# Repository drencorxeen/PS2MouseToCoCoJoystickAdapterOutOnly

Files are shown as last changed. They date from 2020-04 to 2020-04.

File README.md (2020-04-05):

# PS2MouseToCoCoJoystickPortAdapterOutOnly
This project is design to take a PS/2 Mouse and convert it to be usable on a Tandy Radio Shack Color Computer's joystick port.

## Requirements
* 1x ATMega328P-PU chip DIP
* 1x Optional .300" wide 2.54mm pin spaced 28PIN Machine Socket Gold Plated
* 1x MCP4922 DIP
* 1x Optional .300" wide 2.54mm pin spaced 14PIN Machine Socket Gold Plated
* 1x 16MHz or 18.4323MHz crystal(If using 18.432MHz Crystal you will need MiniCore)
* 2x 1N4148 Diones
* 1x 10KΩ Resistor
* 2x 4.7KΩ Resistors
* 2x 470Ω Resistors
* 2x 3mm LEDs
* 2x 0.1µF Ceramic Capacitors
* 2x 22pF Ceramic Capacitors
* 1x MAB6H 6PIN DIN PCB Jack
* 1x mini B female USB connector THT PCB style (for receiving external +5V power)
* 1x 6PIN mini DIN female connector THT PCB style (for connecting PS/2 mouse)

You will also need the PS2Mouse Arduino library by Jacek Kunicki on Github:
https://github.com/rucek/arduino-ps2-mouse

You will also need the MCP49xx Arduino library by Thomas Backman on Github:
https://github.com/exscape/electronics/tree/master/Arduino/Libraries/DAC_MCP49xx

## Disclaimer

As with all DIY electronics projects, this project comes with absolutely no warranty and will not be held liable for any loss or damage caused to your Arduino or vintage PC you used this adapter on. Use at your own risk!

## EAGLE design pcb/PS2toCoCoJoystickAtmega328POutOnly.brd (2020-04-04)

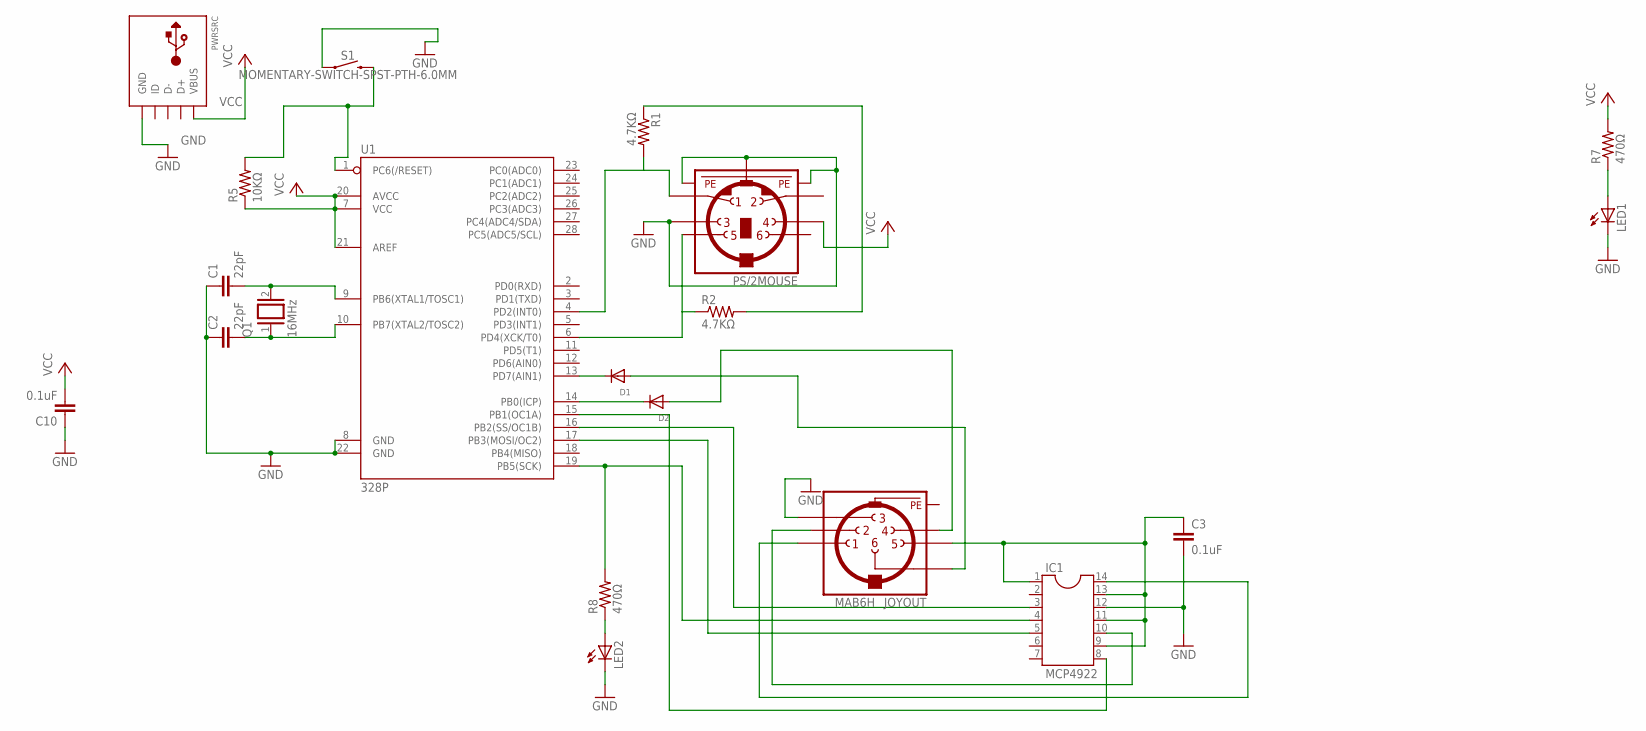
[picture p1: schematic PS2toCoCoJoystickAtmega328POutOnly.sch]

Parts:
C1, C2: 22pF; C2.5-3
C3, C10: 0.1uF; C5B2.5
D1, D2: DIODEDO-1N4148; DO-1N4148
IC1: MCP4922; DIL14
JOYOUT: MAB6H
LED1, LED2: LED3MM
PS/2MOUSE: MINI_DIN_6; M_DIN6
PWRSRC: USBTHM; USB-MINIB-THM
Q1: 16MHz; QS
R1, R2: 4.7KΩ; 0204/7
R5: 10KΩ; 0204/7
R7, R8: 470Ω; 0204/7
S1: MOMENTARY-SWITCH-SPST-PTH-6.0MM; TACTILE_SWITCH_PTH_6.0MM
U1: 328P; DIP28

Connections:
GND: C1.1, C2.1, C3.2, C10.1, IC1.12, JOYOUT.3, JOYOUT.PE, JOYOUT.PE@ (PE), LED1.K (C), LED2.K (C), PS/2MOUSE.3, PS/2MOUSE.SH1 (PE1), PS/2MOUSE.SH2 (PE2), PS/2MOUSE.SH3 (PE3), PWRSRC.GND, S1.1, U1.8 (GND), U1.22 (GND)
unnamed: C1.2, Q1.2, U1.9 (PB6(XTAL1/TOSC1))
unnamed: C2.2, Q1.1, U1.10 (PB7(XTAL2/TOSC2))
unnamed: R5.2, S1.3 (2), U1.1 (PC6(/RESET))
unnamed: D2.A, JOYOUT.4
unnamed: D1.C, U1.13 (PD7(AIN1))
unnamed: D2.C, U1.14 (PB0(ICP))
unnamed: C3.1, IC1.1, IC1.9, IC1.11, IC1.13, JOYOUT.5
unnamed: IC1.3, U1.16 (PB2(SS/OC1B))
unnamed: D1.A, JOYOUT.6
unnamed: IC1.10, JOYOUT.2
unnamed: IC1.14, JOYOUT.1
unnamed: PS/2MOUSE.1, R1.2, U1.4 (PD2(INT0))
unnamed: PS/2MOUSE.6 (5), R2.1, U1.6 (PD4(XCK/T0))
unnamed: IC1.8, U1.15 (PB1(OC1A))
unnamed: IC1.4, R8.2, U1.19 (PB5(SCK))
unnamed: IC1.5, U1.17 (PB3(MOSI/OC2))
unnamed: LED1.A, R7.1
unnamed: LED2.A, R8.1
VCC: C10.2, PS/2MOUSE.5 (4), PWRSRC.VBUS, R1.1, R2.2, R5.1, R7.2, U1.7 (VCC), U1.20 (AVCC), U1.21 (AREF)

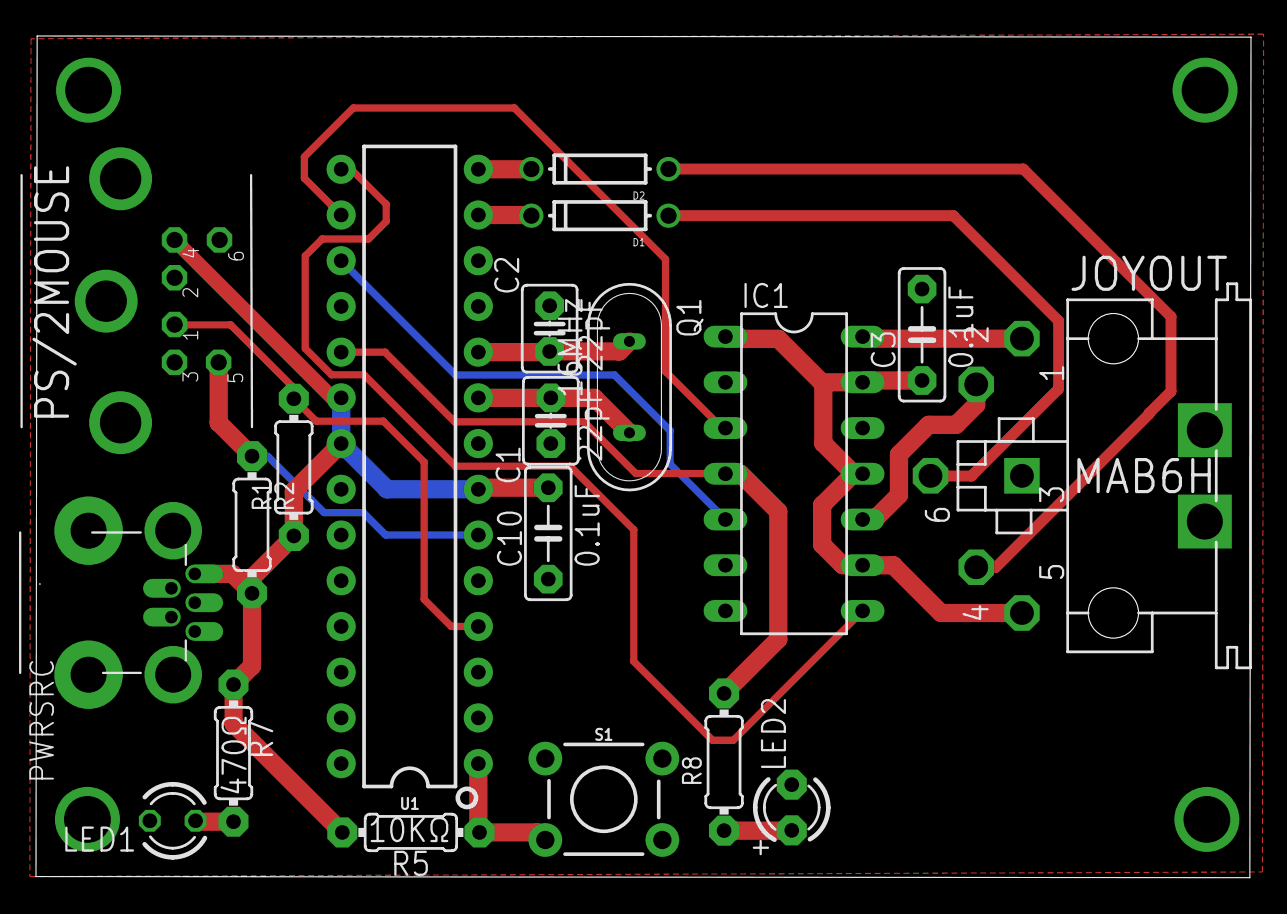
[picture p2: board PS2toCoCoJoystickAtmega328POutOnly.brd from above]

Board: 2 copper layers, 67.5 x 46.8 mm, 20 parts (0 on the bottom side), 20 nets.

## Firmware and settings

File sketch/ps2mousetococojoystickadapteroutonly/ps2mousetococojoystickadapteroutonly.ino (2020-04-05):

// Built using Arduino IDE version 1.8.2
// Include the needed PS2Mouse library.
// Can be acquired from:
// https://github.com/rucek/arduino-ps2-mouse
//
// You will also need to include the DAC_MCP49xx
// library to get this program working.
// You can download the library from:
// https://github.com/exscape/electronics/tree/master/Arduino/Libraries/DAC_MCP49xx
//
#include <avr/wdt.h>
#include <SPI.h>
#include "DAC_MCP49xx.h"
#include "PS2Mouse.h"

#define INVERT_JOY_BUT TRUE

#if defined(INVERT_JOY_BUT)
#define BUTTON LOW
#define BUTTOFF HIGH
#else
#define BUTTON HIGH
#define BUTTOFF LOW
#endif

// The Arduino pin used for the slave select / chip select
#define SS_PIN 10

// The Arduino pin used for the LDAC (output synchronization) feature
#define LDAC_PIN 9

// Set up the DAC. 
// First argument: DAC model (MCP4902, MCP4912, MCP4922)
// Second argument: SS pin (10 is preferred)
// (The third argument, the LDAC pin, can be left out if not used)
DAC_MCP49xx dac(DAC_MCP49xx::MCP4922, SS_PIN, LDAC_PIN);

// Define the PS2 Mouse Data & Clock PINs
// Data Line on the PS/2 6 PIN Mini DIN is PIN 1
// Clock Line on the PS/2 6 PIN Mini DIN is PIN 5
// VCC Line on PS/2 6 PIN Mini DIN is PIN 4
// GND Line on PS/2 6 PIN Mini DIN is PIN 3
#define MDATA_PIN 2
#define MCLOCK_PIN 4

// Set the Min,Max, and Center mouse DAC resolution
#define MMin 0
#define MMax 1023
#define MCent 511

// Set DAC Min and Max
#define DACMax 4095
#define DACMin 0

PS2Mouse mouse(MCLOCK_PIN, MDATA_PIN);

int PCBLED=1;
int But0=8;
int But1=7;
byte MButtons;
byte MMButton;
byte OldB0;
byte OldB1;
byte JoyPass1;

uint16_t CCPOSX=MCent;
uint16_t CCPOSY=MCent;
uint16_t COPOSX=0;
uint16_t COPOSY=0;
uint16_t MPPOSX;
uint16_t MPPOSY;
int16_t TCPOSX;
int16_t TCPOSY;
int16_t OLDX;
int16_t OLDY;

void setup(void) {
  // Here we enable the watchdog system and set it it to 1 second.
  // This should help keep the system resetting till the PS/2 Mouse
  // is ready to be setup.
  wdt_enable(WDTO_1S);
  //pinMode(PCBLED, OUTPUT);
  JoyPass1=0;
  //digitalWrite(PCBLED, LOW);
  mouse.initialize();
  // Set the SPI frequency to 1 MHz (on 16 MHz Arduinos), to be safe.
  // DIV2 = 8 MHz works for me, though, even on a breadboard.
  // This is not strictly required, as there is a default setting.
  dac.setSPIDivider(SPI_CLOCK_DIV16);
  // Use "port writes", see the manual page. In short, if you use pin 10 for
  // SS (and pin 7 for LDAC, if used), this is much faster.
  // Also not strictly required (no setup() code is needed at all).
  dac.setPortWrite(false);
  // Pull the LDAC pin low automatically, to synchronize output
  // This is true by default, however.
  dac.setAutomaticallyLatchDual(true);
  //Serial.begin(115200);
  pinMode(But1, OUTPUT);
  pinMode(But0, OUTPUT);
  delay(20);
  digitalWrite(But0, BUTTOFF);
  digitalWrite(But1, BUTTOFF);
  //wdt_enable(WDTO_2S);
  dac.output2(map(CCPOSX,MMin,MMax,DACMin,DACMax), map(CCPOSY,MMax,MMin,DACMin,DACMax));
  //digitalWrite(PCBLED, HIGH);
}

void loop (void) {
  wdt_reset();
  MouseData data = mouse.readData();
  MButtons = data.status & 3;
  MMButton = data.status & 4;

    switch(MButtons) {
      case 0:
        digitalWrite(But0, BUTTOFF);
        digitalWrite(But1, BUTTOFF);
        break;
      case 1:
        digitalWrite(But0, BUTTON);
        digitalWrite(But1, BUTTOFF);
        break;
      case 2:
        digitalWrite(But0, BUTTOFF);
        digitalWrite(But1, BUTTON);
        break;
      case 3:
        digitalWrite(But0, BUTTON);
        digitalWrite(But1, BUTTON);
        break;
    }
    if ( (data.position.x != 0)||(data.position.y != 0) ) {
      COPOSX = CCPOSX;
      TCPOSX = CCPOSX + data.position.x;
      CCPOSX = CCPOSX + data.position.x;
      if ( TCPOSX > MMax ) {
        CCPOSX = MMax;
      } else {
        if ( TCPOSX < MMin ) {
          CCPOSX = MMin;
        }
      }
      COPOSY = CCPOSY;
      TCPOSY = CCPOSY + data.position.y;
      CCPOSY = CCPOSY + data.position.y;
      if ( TCPOSY > MMax ) {
        CCPOSY = MMax;
      } else {
        if ( TCPOSY < MMin ) {
          CCPOSY = MMin;
        }
      }
      if ( (COPOSX != CCPOSX)||(COPOSY != CCPOSY) ) {
        dac.output2(map(CCPOSX,MMin,MMax,DACMin,DACMax), map(CCPOSY,MMax,MMin,DACMin,DACMax));
      }
    }
  // Here we set the delay before we go back to the
  // start of the loop. Minimum delay of 20 is required
  // but something higher can be used to liking.
  delay(31);
}

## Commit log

2020-04-04 Added the schematic and pcb files for the project.
    [PS2toCoCoJoystickAtmega328POutOnly.brd, PS2toCoCoJoystickAtmega328POutOnly.sch]
2020-04-05 Updated README.md to reflect parts list and where to get Arduino Libraries required to build the firmware.
2020-04-05 Updated Arduino sketch file to remove ifdef's based on AVR since MiniCore doesn't seem to set this. This change was needed as some PS/2 mice have slow µCU's that don't always come up in time for the 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
    [ps2mousetococojoystickadapteroutonly.ino]

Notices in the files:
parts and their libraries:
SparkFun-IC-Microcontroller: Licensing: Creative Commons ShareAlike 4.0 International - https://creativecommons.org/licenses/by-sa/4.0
